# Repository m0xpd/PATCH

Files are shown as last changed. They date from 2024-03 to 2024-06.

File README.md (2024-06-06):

# PATCH
PATCH is a simple modular patchbay project for Eurorack.

<p width=100%, align="center">
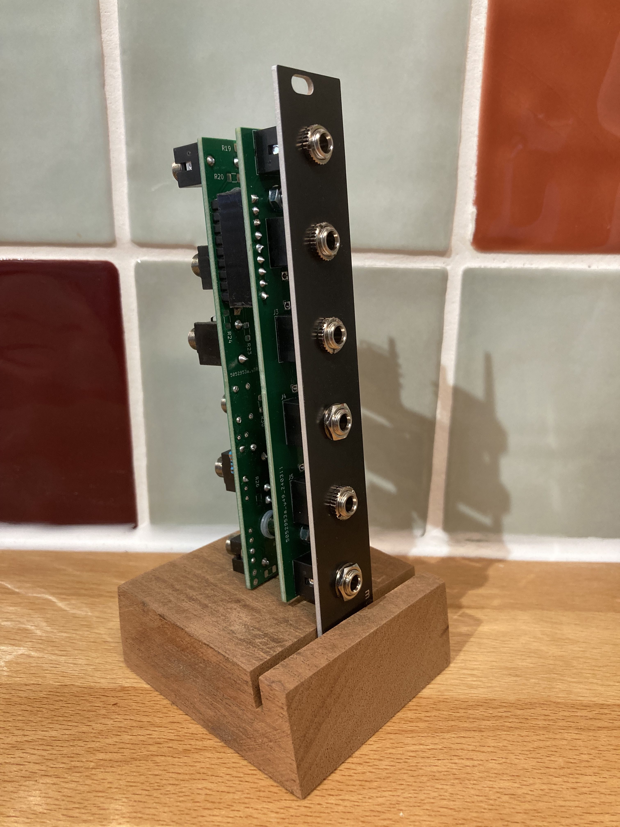
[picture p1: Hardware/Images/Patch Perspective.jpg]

</p>

PATCH started with an application to develop a simple interface to my [UMC1820 Audio Interface](https://www.behringer.com/product.html?modelCode=0805-AAN) and my [FX2000 Effects Processor](https://www.behringer.com/product.html?modelCode=P0A3P), both of which have rear-mounted audio I/O and require some input attentuators to allow them to work as I wish in my system. A patchbay is the perfect way to impose order on the tangle of wires, to avoid searching on the back of cases (especially if they're stacked or racked) and is also the logical place to implement attenuating pads, where required. 

The image below shows two PATCH patchbay modules (inside the yellow rounded rectangle) implementing the complete interface to the UMC1820 and FX2000

<p width=100%, align="center">
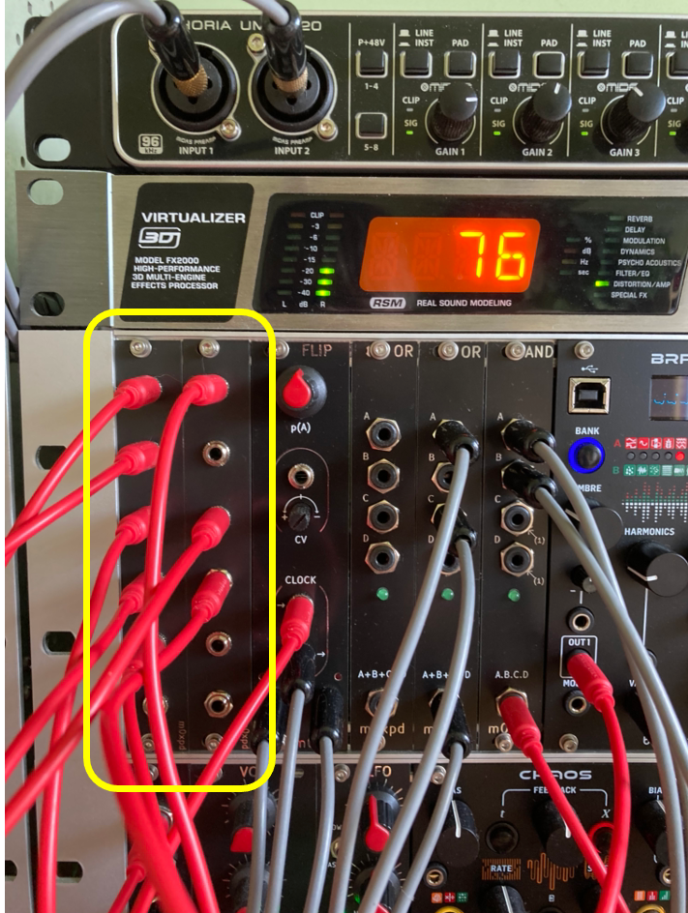
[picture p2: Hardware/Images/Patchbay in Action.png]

</p>

Note that the UMC1820 [does not need attenuators to handle modular signals directly](https://modwiggler.com/forum/viewtopic.php?p=2936306#p2936306). Indeed, it is specified to be capable of handling inputs up to +18dBu. However, this requires that the inputs are set to LINE (obviously), that the PADs are applied, and the GAIN controls are set way down near the bottom of their travel. I have been pleased to discover that in addition to service as front end of a DAW (or similar application), the UMC1820 also operates usefuly as a stand-alone mixer, with 8 channels going in and direct output to the system monitors. In this role, some external attenuation on the inputs is helpful, as it allows the GAIN controls to operate as Level 'faders' over a wider range, with more useful resolution. On the other hand, the FX2000 is specified only to handle inputs up to +4dBu and my modular was easily able to overload its inputs; an external attenuator is certainly required in this case. 

The basic PATCH configuration which services this motivating application, seen in the photos above, is realised by three components: a [front panel](https://github.com/m0xpd/PATCH/tree/main/Hardware/Front%20Panel#readme), a [socket board](https://github.com/m0xpd/PATCH/tree/main/Hardware/Socket%20Board#readme), and a [passive board](https://github.com/m0xpd/PATCH/tree/main/Hardware/Passive%20Board#readme). 

The passive board includes pi networks between the 3.5mm jack sockets at input and output of each channel and provides options to normal the 'tip switches' on the jacks to ground if the channel is configured as an input. This tip normalisation is achieved using 1206 surface mount (0 Ohm) resistors (as I figure not many people will bother to use them), whilst the rest of the board uses through-hole components. Partially populating the resistors of the pi network gives the option to set up a potential divider to drop the signal level in either direction, or to set a unity gain 'straight wire' connection. The system shown above has a 24dB pad on the top two channels and two send/return loops implemented on the next four sockets, with 12dB pads on the sends and straight-wire returns.

Populating the pads is up to you - I'm using a 15k / 1k potential divider for the -24dB and 3k3 / 1k1 potential divider for the -12dB. HOWEVER, you should remember that the device you're plugging into has finite (and possibly LOW) input impedance, which will sit in parallel with the botttom resistor of the potential divider, so either don't take the open-circuit calculations too seriously, or account for this loading in your design!

The Passive board, which makes up PATCH's standard patchbay configuration, houses a set of 3.5mm sockets which face to the rear, mirroring those on the front panel. Standard Eurorack patch leads (or other leads made up for custom applications, such as the 3.5 mm to 6.5mm right angle jacks I've made to hook up to the back of my FX2000) connect to these sockets, when the patchbay is used in the modular:

<p width=100%, align="center">
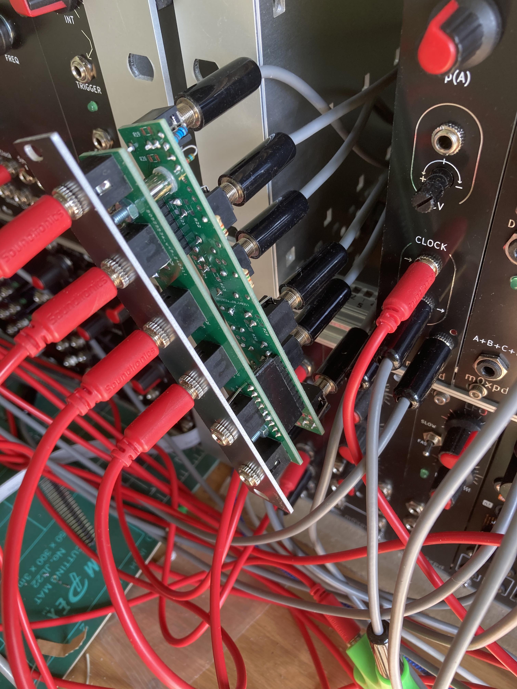
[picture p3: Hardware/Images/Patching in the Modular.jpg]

</p>

***

The minimum order quantity at [JLC](https://jlcpcb.com/) (typical of all pcb houses) for the front panel and socket board left me with some spare resources after I'd finished my interface to the Behringer "off-board" units, so I also develped a [passive multiple board](https://github.com/m0xpd/PATCH/tree/main/Hardware/Passive%20Multiple%20Board#readme), and a [buffered multiple board](https://github.com/m0xpd/PATCH/tree/main/Hardware/Buffered%20Multiple%20Board#readme) so as not to waste the relatively expensive Aluminium front panels. 

These multiples share the front panel and the socket board with the basic patchbay design, but use a different final board. 

The complete set of PATCH system panels are seen below.

<p width=100%, align="center">
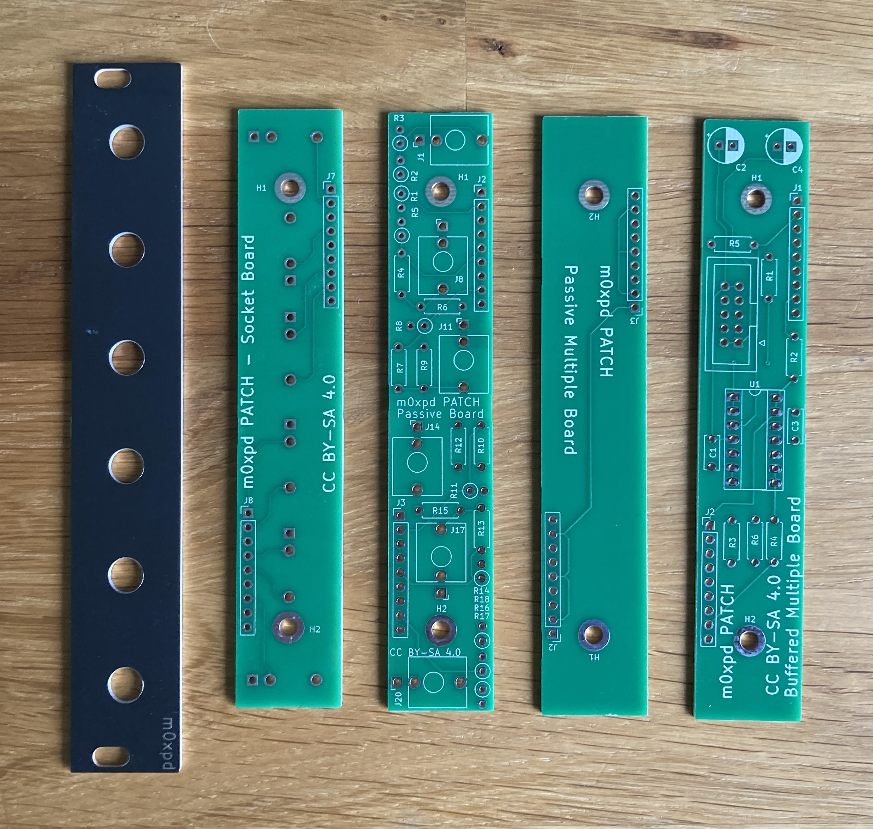
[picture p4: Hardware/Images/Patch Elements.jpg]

</p>

Both the passive multiple and the buffered multiple are organised as two 1 in, 2 out sections, with the input to the second section normalled to the output of the first, such that the multiple can be operated as two 1 -> 2 units or one 1 -> 4 unit.

A PATCH buffered multiple is seen below:

<p width=100%, align="center">
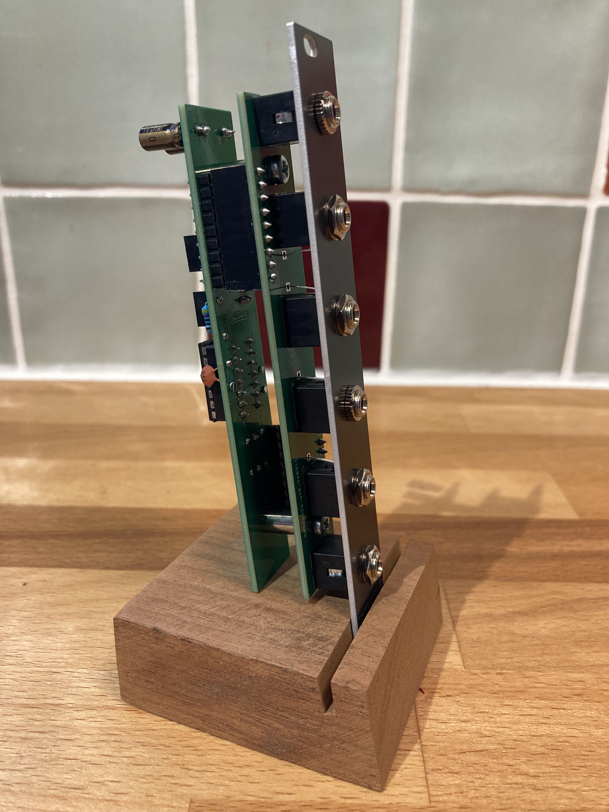
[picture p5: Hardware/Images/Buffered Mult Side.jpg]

</p>

All the system components are described in the [hardware folder](https://github.com/m0xpd/PATCH/tree/main/Hardware#readme), where schematics, PCB layouts and front panel designs are presented as [KiCad](https://www.kicad.org/) projects.

# PATCH Multicore

The PATCH system now (as at 5 June 2024) also has a multicore option, realised by a pair of boards. The multicore functionality was first suggested by "CoogLFish", within the "Issues" section of this repo and whose inspiration is acknowledged.

The boards are offered in two forms. First, the ["low budget"](https://github.com/m0xpd/PATCH/tree/main/Hardware/RJ45%20Board#readme) option uses a single UTP cable to join two modules to make a six channel multicore]. Second, the ["high end" alternative](https://github.com/m0xpd/PATCH/tree/main/Hardware/Twin%20RJ45%20Board#readme) uses two UTP cables to achieve the same goal with the possibility of slightly better crosstalk performance. This "Twin" system will also work with cables with shielded twisted pairs such as CAT8 and offer some performance advantages - but I have not yet formally tested this to determine how big the performance advantage (over either the single cable solution or UTP cables) really is. I use CAT6 cables over 1.5m and have not yet noticed issues.

# Other PATCH System Components

There may be still more additions to the PATCH system in future - I have a couple more ideas, but there are lots of other potential projects competing for attention, so watch this space, but don't hold your breath.

# License

PATCH is published under [CC BY-SA 4.0 license.](https://github.com/m0xpd/PATCH/blob/main/LICENSE.txt)

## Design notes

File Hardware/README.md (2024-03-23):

This folder contains design files for components of the PATCH modular Eurorack patchbay system.

There are schematics, PCB layouts and a Front Panel design in [KiCad](https://www.kicad.org/) format.

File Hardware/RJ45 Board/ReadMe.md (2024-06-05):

# PATCH RJ45 Board

This folder contains details of a RJ45 board, which allows the Patch system to use a CAT5 cable to provide a six channel link between two locations 
in large a modular case. This idea was propted by a suggestion made in response to the initial Patch system by "CoogLFish" - to whom I am grateful. 

The RJ45 board is seen below in populated and unpopulated form:
<p width=100%, align="center">
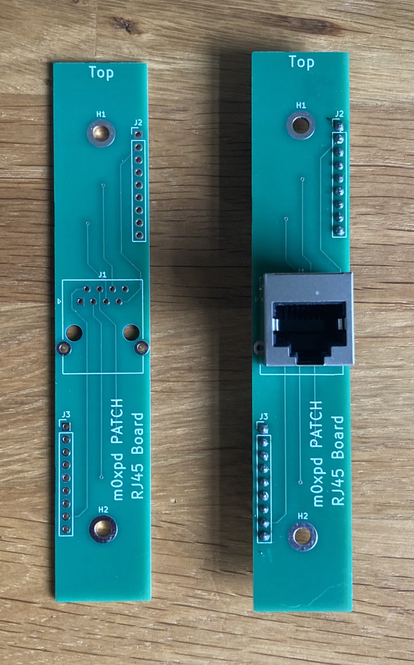
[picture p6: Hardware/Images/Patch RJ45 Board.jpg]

</p>

The signals from all six sockets on the Patch socket board are passed down six of the conductors of the RJ45 cable. This idea horrifies the engineer in me, but it must work well enough, as 7 such signals are passed down the same type of cable in [this commercial solution](https://www.doepfer.de/A1809.htm) - if it's good enough for Dieter!

The RJ-45 board plugs onto the back of a [Front Panel](https://github.com/m0xpd/PATCH/tree/main/Hardware/Front%20Panel#readme) / [socket board](https://github.com/m0xpd/PATCH/tree/main/Hardware/Socket%20Board#readme) 
combination in the same way as the rest of the PATCH family to make a full module:

<p width=100%, align="center">
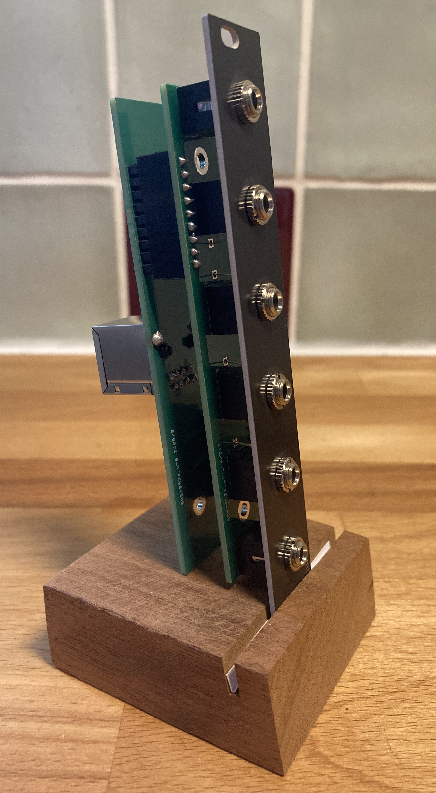
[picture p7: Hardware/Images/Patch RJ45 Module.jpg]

</p>

Two of these modules, one at either end of a standard 'network cable', make a useful multicore. In use, with a 1.5m CAT6 cable, I didn't notice any 
issues of signal loss, crosstalk or hum (etc). But the idea still horrifies me. 

So, I decided to exploit the "twisted pair" construction of network cables and build a Twin RJ45 board, which you can find [here](https://github.com/m0xpd/PATCH/tree/main/Hardware/Twin%20RJ45%20Board#readme) - to hell with the expense!

Those who want to stick with a single cable will find the KiCad design files for the single RJ-45 board in this folder - there's a KiCad project, a schematic and a PCB file.

Like the rest of the PATCH famiy, the RJ45 board is published under a CC BY-SA 4.0 [License](https://github.com/m0xpd/PATCH/blob/main/LICENSE.txt).

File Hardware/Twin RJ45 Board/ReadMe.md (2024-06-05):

# PATCH Twin RJ45 Board

This folder contains details of a Twin RJ45 board, which allows the Patch system to use two CAT5 (or better) cables to provide a six channel link 
between two locations in large a modular case. This idea was propted by a suggestion made in response to the initial PATCH system by "CoogLFish" - 
to whom I am grateful. 

The Twin RJ45 board is seen below in populated and unpopulated form:
<p width=100%, align="center">
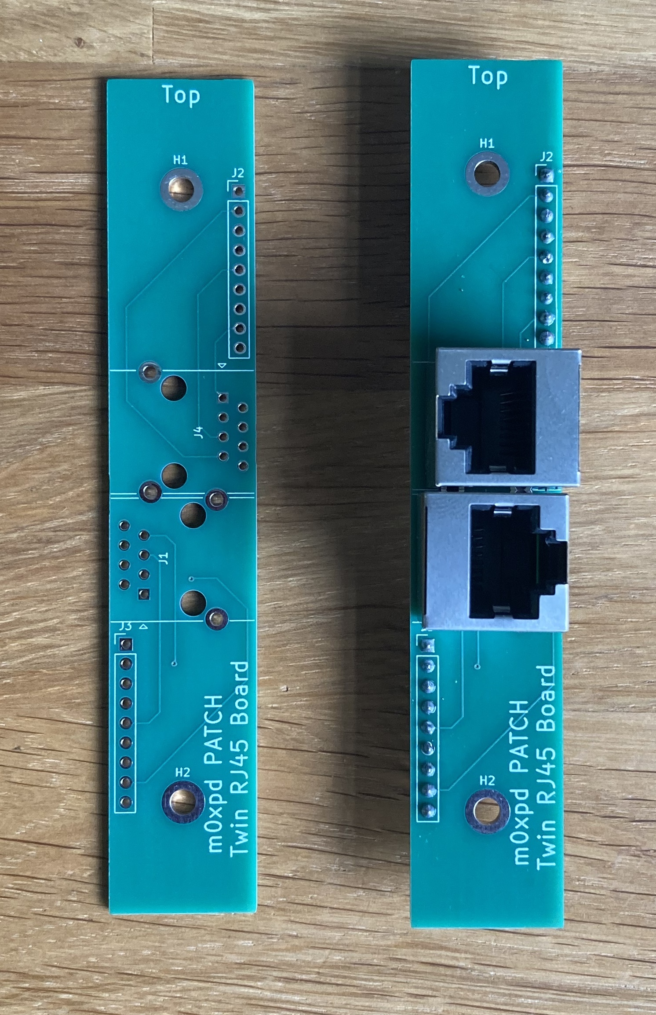
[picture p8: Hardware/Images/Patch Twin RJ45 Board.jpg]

</p>

The signals from all six sockets on the PATCH [socket board](https://github.com/m0xpd/PATCH/tree/main/Hardware/Socket%20Board#readme) are passed down three pairs of conductors in each cable connected to the two RJ45 sockets. 
These conductor pairs are arranged in twisted pairs, which should help to slightly reduce crosstalk between channels (although - of course - these 
are not balanced pairs in modular application as they would be in balanced audio interfaces or current loop data signalling). If you really want to go mad, you could use CAT8 cables with individual
screening around each pair - but if you care that much, you're probably already too busy chasing Unicorns.

The assembled module is seen below:
<p width=100%, align="center">
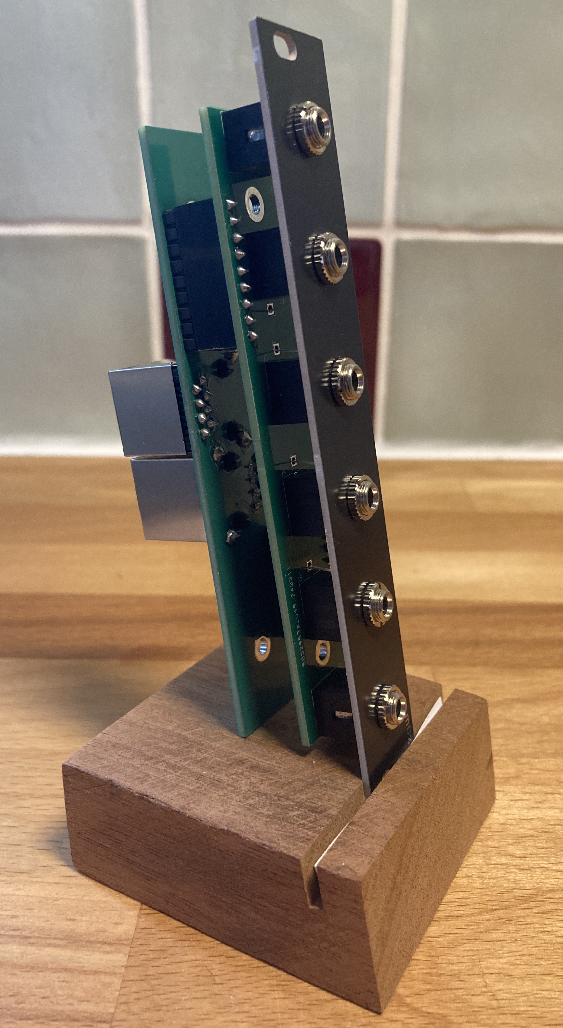
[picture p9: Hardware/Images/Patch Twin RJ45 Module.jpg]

</p>

and its role as a multicore is understood from this image:

<p width=100%, align="center">
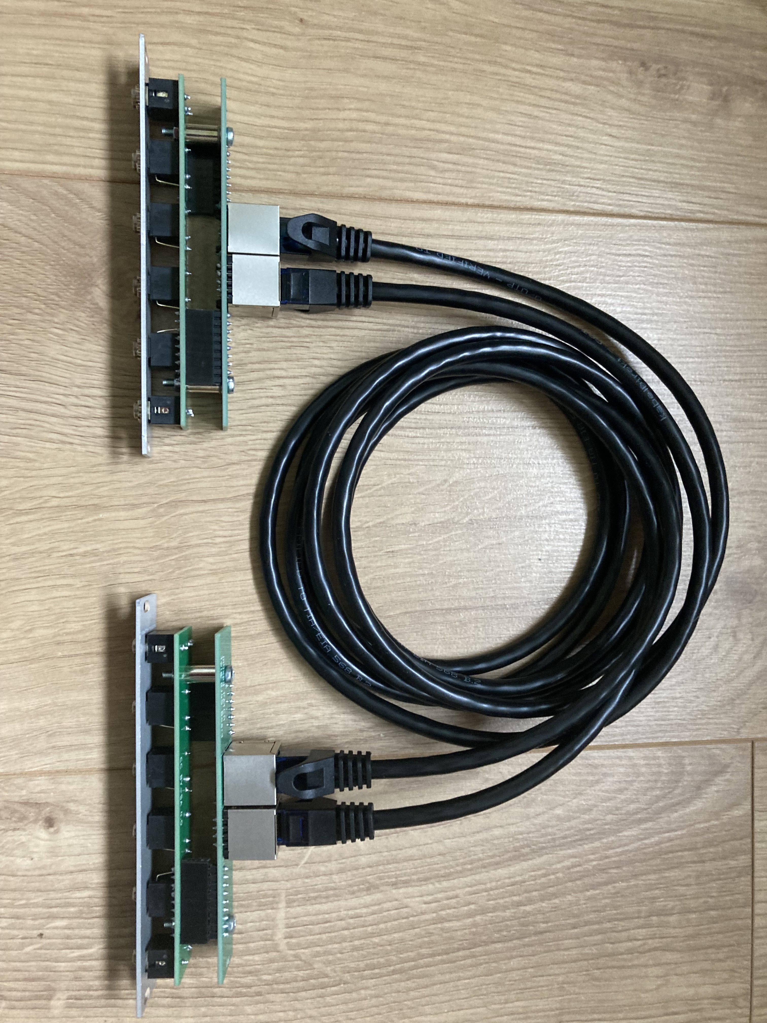
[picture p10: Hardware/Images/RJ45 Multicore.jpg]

</p>

A KiCad project, formed from a project file, a schematic and a pcb file, can be found in this folder.

Like the rest of the PATCH famiy, the Twin RJ45 board is published under a CC BY-SA 4.0 [License](https://github.com/m0xpd/PATCH/blob/main/LICENSE.txt).

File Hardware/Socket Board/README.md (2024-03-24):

# Socket Board

This folder contains design files for the "Socket Board", which is a common element of all PATCH applications. The files are in [KiCad](https://www.kicad.org/) format.

The Socket Board carries six "[Thonkiconn](https://www.thonk.co.uk/shop/thonkiconn/)" 3.5mm sockets (by which it mounts to the Front Panel) and two 9*1 0.1 inch female header sockets (by which other PATCH boards plug onto the back of the socket board. I find it convenient to cut these 9-way receptacles down from 40-way units, which I keep in stock.

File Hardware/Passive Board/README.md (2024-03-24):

# Passive Board

This folder contains design files of the "Passive Board" which, in conjunction with the Front Panel and Socket Board, implements a simple six-channel patchbay. 
The design files are presented as a [KiCad](https://www.kicad.org/) project.

The Passive Board hosts six "[Thonkiconn](https://www.thonk.co.uk/shop/thonkiconn/)" 3.5mm sockets, which mirror those on the front panel and two 9*1 0.1 inch headers, which mount the Passive Board onto 
the Socket Board. 

A set of 12 positions for 1206 surface mount resistors on the bottom side of the board allow 0 Ohm links to be fitted, which normal the Tips of the sockets 
(on the Passive and Socket board) to ground, as required.

On the top side of the board, positions are provided for through hole resistors forming a "pi network" to be placed between each socket on the Socket Board and 
the corresponding socket on the Passive Board. This allows (by leaving one resistor unpopulated) for a potential divider to be fitted to attentuate the signal 
in either direction or (by fitting a 0 Ohm link - i.e. a wire  in the resistor position at the top of th 'pi' and leaving the other resistors unpopulated), making 
the channel a straight-wire connection.

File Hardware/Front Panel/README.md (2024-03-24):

# Front Panel

This folder contains design files for a front panel for the PATCH system, expressed as a [KiCad](https://www.kicad.org/) project.

Remember that the schematic is 'empty' - the front panel has no electrical connections.

The front panel has no labels/annotation, because each instance of the system will be put to different use; you can add labels convenient to your own application if you need to.

I find it convenient at least to use different nuts (i.e. knurled or hex) on the sockets to remind me which are inputs and which are outputs, from which I can remember the configuration of the PATCH module. If you are less stingy than me, you could even use coloured nuts!

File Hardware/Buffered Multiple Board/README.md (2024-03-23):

# Buffered Multiple Board

This folder contains design files for the Buffered Multiple Board which (in conjuntion with the Socket Board and Front Panel) form an active, Buffered Multiple. 
The design files are presented as a [KiCad](https://www.kicad.org/) project.

The Buffered Multiple Board hosts two 9 * 1, 0.1 inch headers (to mount it on to the Socket Board),  a standard 2*5 Eurorack Power Header and filtering capacitors. 
It also hosts a quad op-amp (I used a TL084, but anything similar will work), the stages of which are used as voltage followers, and a few resistors to set the 
input and source impedance. 

The resulting buffered multiple is organised as two 1 in, 2 out sections, with the input to the second section normalled to the output of the first, 
such that the module can be operated as two 1 -> 2 multiples or one 1 -> 4 multiple.

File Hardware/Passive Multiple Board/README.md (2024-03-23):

# Passive Multiple Board

This folder contains design files for the Passive Multiple Board which (in conjuntion with the Socket Board and Front Panel) form a Passive Multiple. 
The design files are presented as a [KiCad](https://www.kicad.org/) project.

The Passive Multiple Board is trivial, hosting only two 9*1 0.1 inch headers (to mount it on to the Socket Board) and containing tracks between the 
poles of these headers to make the electrical connections which define the circuit (see the Schematic).

The resulting passive multiple is organised as two 1 in, 2 out sections, with the input to the second section normalled to the output of the first, 
such that the module can be operated as two 1 -> 2 multiples or one 1 -> 4 multiple.

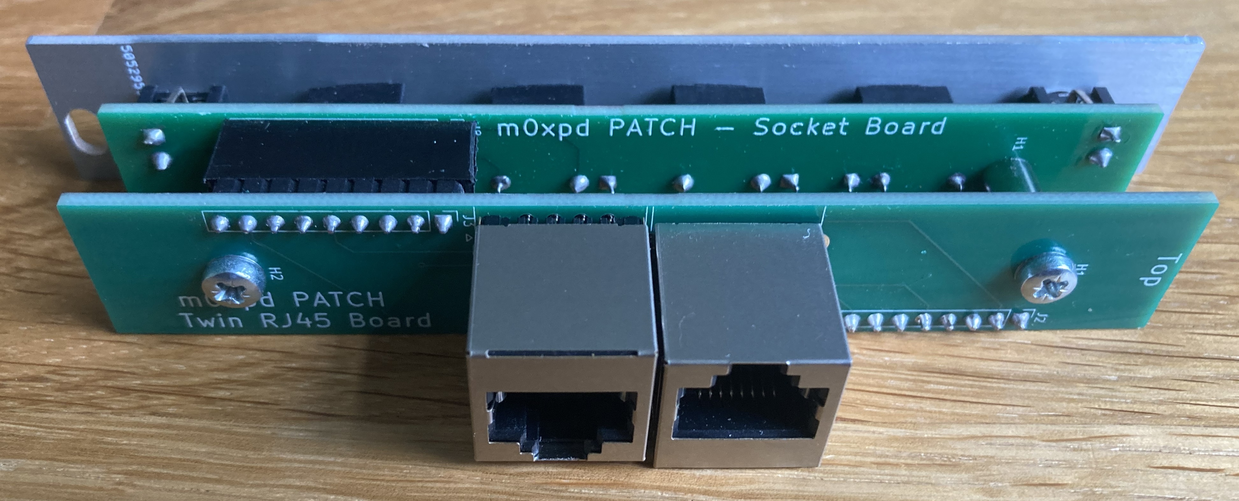
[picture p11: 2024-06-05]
Hardware/Images/Twin RJ45 Module Rear.jpg

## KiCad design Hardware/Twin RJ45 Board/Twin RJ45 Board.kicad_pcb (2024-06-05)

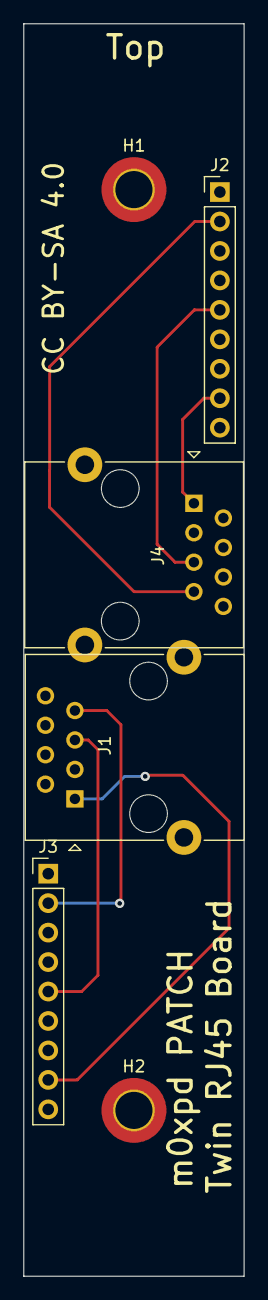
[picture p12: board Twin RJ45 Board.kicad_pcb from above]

Board: 2 copper layers, 19.0 x 108.0 mm, 6 parts (0 on the bottom side), 7 nets.

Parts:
H1, H2: MountingHole_Pad; MountingHole_3.2mm_M3_DIN965_Pad_TopBottom
J1, J4: RJ45_Shielded; RJ45_Ninigi_GE
J2, J3: Conn_01x09; PinHeader_1x09_P2.54mm_Vertical

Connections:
GND: H1.1, H2.1, J1.2, J1.3, J1.4, J1.6, J1.8, J1.SH, J2.3, J2.6, J2.9, J3.3, J3.6, J3.9, J4.2, J4.3, J4.4, J4.6, J4.8, J4.SH
unnamed: J2.2, J4.7
unnamed: J2.5, J4.5
unnamed: J2.8, J4.1
unnamed: J1.7, J3.2
unnamed: J1.5, J3.5
unnamed: J1.1, J3.8

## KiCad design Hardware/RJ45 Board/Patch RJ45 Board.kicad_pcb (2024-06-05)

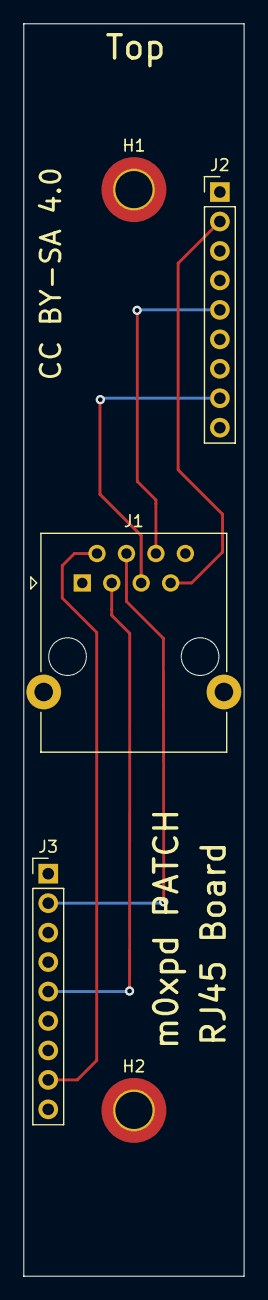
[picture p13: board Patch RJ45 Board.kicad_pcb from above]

Board: 2 copper layers, 19.0 x 108.0 mm, 5 parts (0 on the bottom side), 7 nets.

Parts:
H1, H2: MountingHole_Pad; MountingHole_3.2mm_M3_DIN965_Pad_TopBottom
J1: RJ45_Shielded; RJ45_Ninigi_GE
J2, J3: Conn_01x09; PinHeader_1x09_P2.54mm_Vertical

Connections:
GND: H1.1, H2.1, J1.1, J1.8, J1.SH, J2.3, J2.6, J2.9, J3.3, J3.6, J3.9
unnamed: J1.7, J2.2
unnamed: J1.6, J2.5
unnamed: J1.5, J2.8
unnamed: J1.4, J3.2
unnamed: J1.3, J3.5
unnamed: J1.2, J3.8

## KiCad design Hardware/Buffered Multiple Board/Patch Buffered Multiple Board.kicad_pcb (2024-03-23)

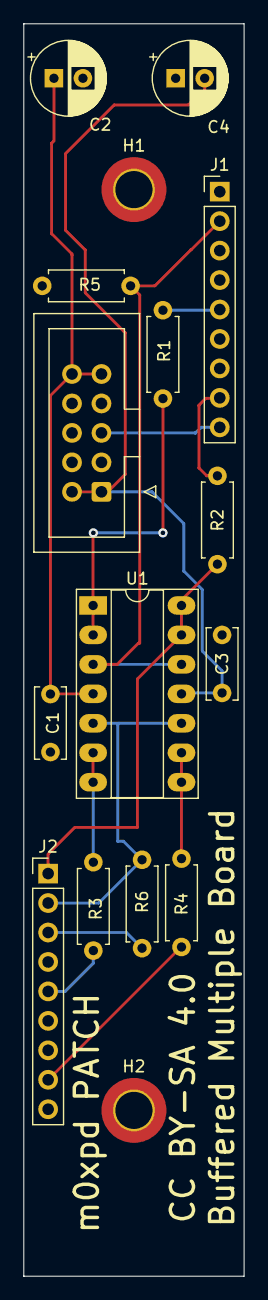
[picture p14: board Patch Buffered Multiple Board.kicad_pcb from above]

Board: 2 copper layers, 19.0 x 108.0 mm, 16 parts (0 on the bottom side), 13 nets.

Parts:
C1, C3: 0.1u; C_Disc_D6.0mm_W2.5mm_P5.00mm
C2, C4: 22u; CP_Radial_D6.3mm_P2.50mm
H1, H2: MountingHole_Pad; MountingHole_3.2mm_M3_DIN965_Pad_TopBottom
J1, J2: Conn_01x09; PinHeader_1x09_P2.54mm_Vertical
R1, R2, R3, R4, R5, R6: R; R_Axial_DIN0207_L6.3mm_D2.5mm_P7.62mm_Horizontal
U1: TL084; DIP-14_W7.62mm_Socket_LongPads
X1: 2510-; IDC-Header_2x05_P2.54mm_Vertical

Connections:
+12V: C1.1, C2.1, U1.4 (V+), X1.9 (KL), X1.10 (KL)
-12V: C3.2, C4.2, U1.11 (V-), X1.1 (KL), X1.2 (KL)
GND: C1.2, C2.2, C3.1, C4.1, H1.1, H2.1, J1.3, J1.6, J1.9, J2.3, J2.6, J2.9, R5.1, R6.1, X1.3 (KL), X1.4 (KL), X1.5 (KL), X1.6 (KL), X1.7 (KL), X1.8 (KL)
IN1: J1.2, R5.2, U1.3 (+), U1.12 (+)
IN2: J2.2, R6.2, U1.5 (+), U1.10 (+)
unnamed: R1.1, U1.1, U1.2 (-)
unnamed: R3.1, U1.6 (-), U1.7
unnamed: R4.1, U1.8, U1.9 (-)
OUT1: J1.5, R1.2
OUT2: J1.8, R2.2
OUT2A: J2.1, R2.1, U1.13 (-), U1.14
OUT3: J2.5, R3.2
OUT4: J2.8, R4.2

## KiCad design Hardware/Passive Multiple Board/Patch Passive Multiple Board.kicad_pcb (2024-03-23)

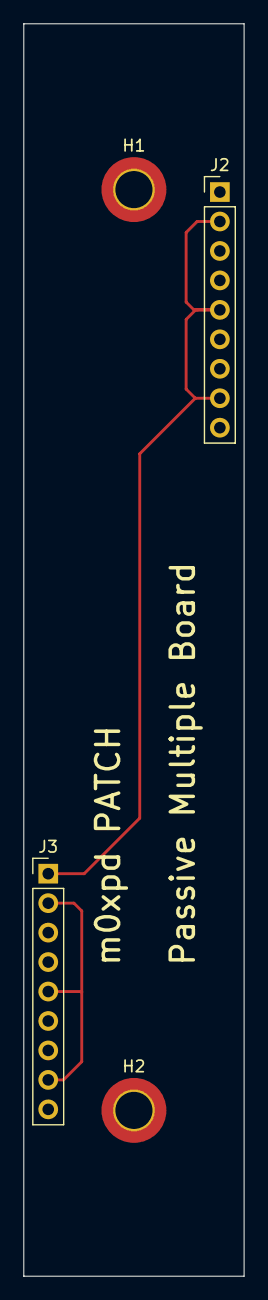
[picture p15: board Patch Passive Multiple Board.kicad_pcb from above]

Board: 2 copper layers, 19.0 x 108.0 mm, 4 parts (0 on the bottom side), 3 nets.

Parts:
H1, H2: MountingHole_Pad; MountingHole_3.2mm_M3_DIN965_Pad_TopBottom
J2, J3: Conn_01x09; PinHeader_1x09_P2.54mm_Vertical

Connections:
GND: H1.1, H2.1, J2.3, J2.6, J2.9, J3.3, J3.6, J3.9
unnamed: J2.2, J2.5, J2.8, J3.1
unnamed: J3.2, J3.5, J3.8

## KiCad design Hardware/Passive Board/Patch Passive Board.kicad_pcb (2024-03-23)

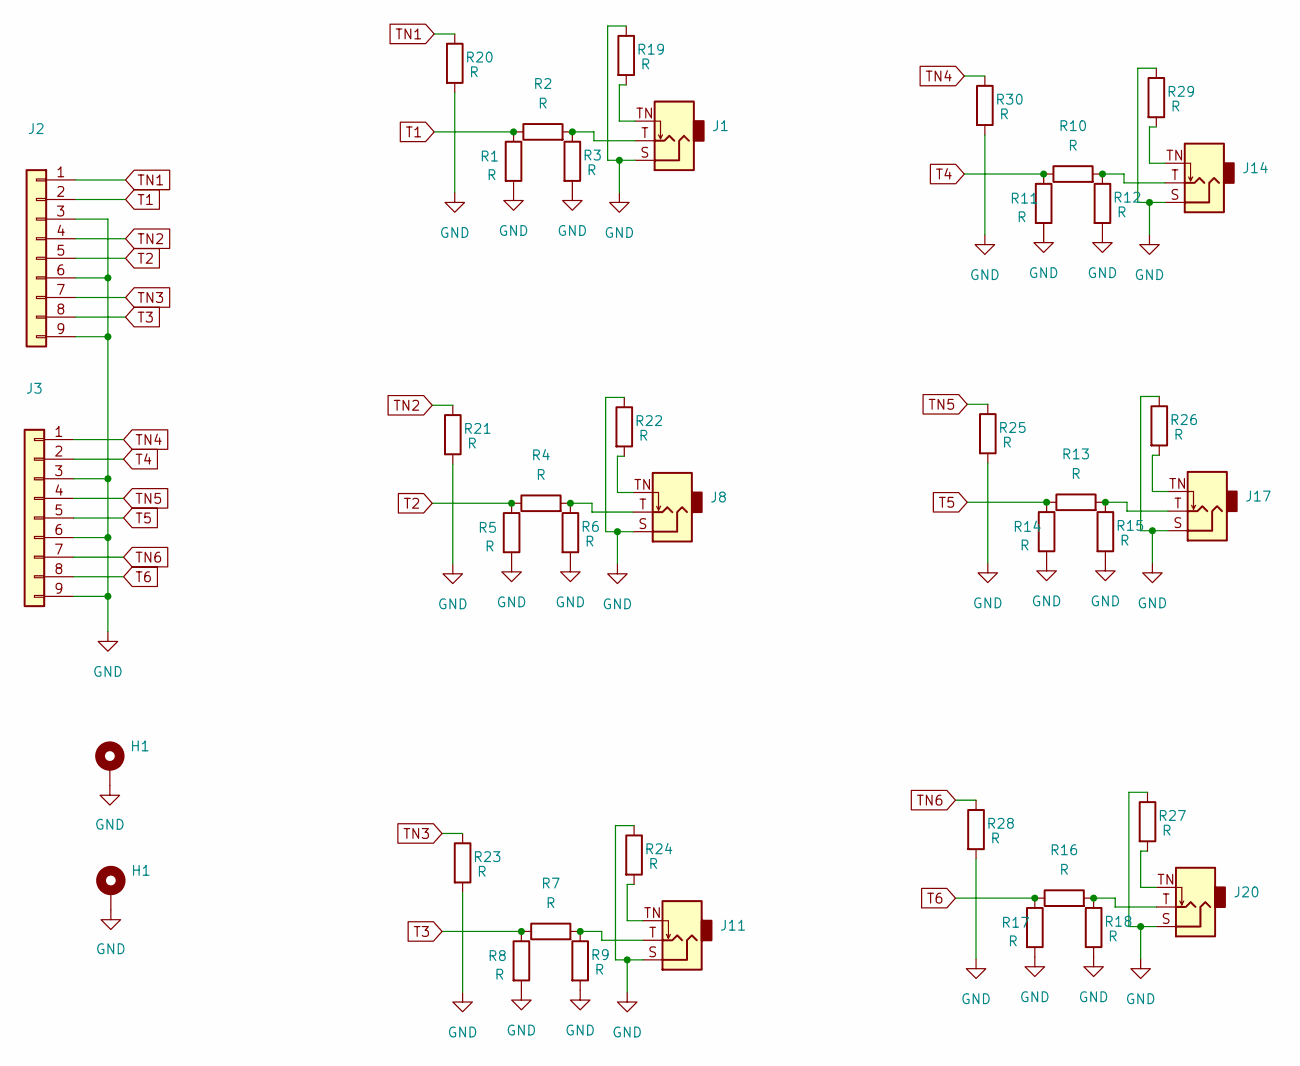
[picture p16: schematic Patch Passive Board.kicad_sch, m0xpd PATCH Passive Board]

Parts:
H1: MountingHole_Pad; MountingHole_3.2mm_M3_DIN965_Pad_TopBottom
J1, J8, J11, J14, J17, J20: AudioJack2_SwitchT; Jack_3.5mm_QingPu_WQP-PJ398SM_Vertical_CircularHoles
J2, J3: Conn_01x09; PinHeader_1x09_P2.54mm_Vertical
R1, R2, R3, R5, R8, R11, R14, R16, R17, R18: R; R_Axial_DIN0207_L6.3mm_D2.5mm_P2.54mm_Vertical
R4, R6, R7, R9, R10, R12, R13, R15: R; R_Axial_DIN0207_L6.3mm_D2.5mm_P7.62mm_Horizontal
R19, R20, R21, R22, R23, R24, R25, R26, R27, R28, R29, R30: R; R_1206_3216Metric_Pad1.30x1.75mm_HandSolder

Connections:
GND: H1.1, J1.S, J2.3, J2.6, J2.9, J3.3, J3.6, J3.9, J8.S, J11.S, J14.S, J17.S, J20.S, R1.2, R3.2, R5.2, R6.2, R8.2, R9.2, R11.2, R12.2, R14.2, R15.2, R17.2, R18.2, R19.1, R20.2, R21.2, R22.1, R23.2, R24.1, R25.2, R26.1, R27.1, R28.2, R29.1, R30.2; also elsewhere on the board
unnamed: J1.T, R2.2, R3.1
unnamed: J1.TN, R19.2
unnamed: J8.T, R4.2, R6.1
unnamed: J8.TN, R22.2
unnamed: J11.T, R7.2, R9.1
unnamed: J11.TN, R24.2
unnamed: J14.T, R10.2, R12.1
unnamed: J14.TN, R29.2
unnamed: J17.T, R13.2, R15.1
unnamed: J17.TN, R26.2
unnamed: J20.T, R16.2, R18.1
unnamed: J20.TN, R27.2
T1: J2.2, R1.1, R2.1
T2: J2.5, R4.1, R5.1
T3: J2.8, R7.1, R8.1
T4: J3.2, R10.1, R11.1
T5: J3.5, R13.1, R14.1
T6: J3.8, R16.1, R17.1
TN1: J2.1, R20.1
TN2: J2.4, R21.1
TN3: J2.7, R23.1
TN4: J3.1, R30.1
TN5: J3.4, R25.1
TN6: J3.7, R28.1

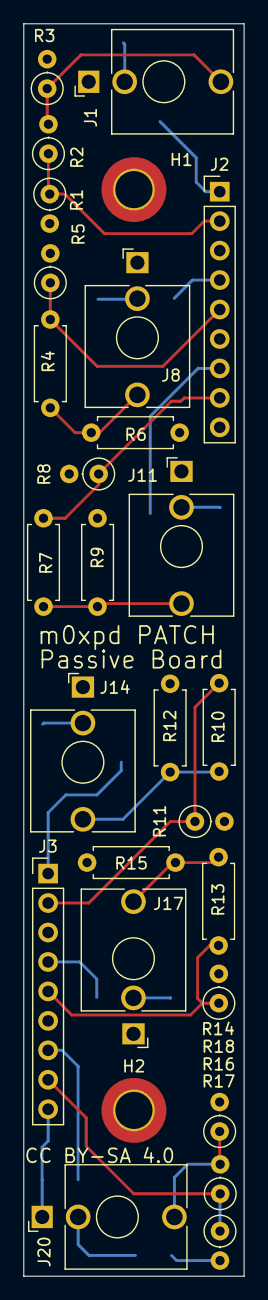
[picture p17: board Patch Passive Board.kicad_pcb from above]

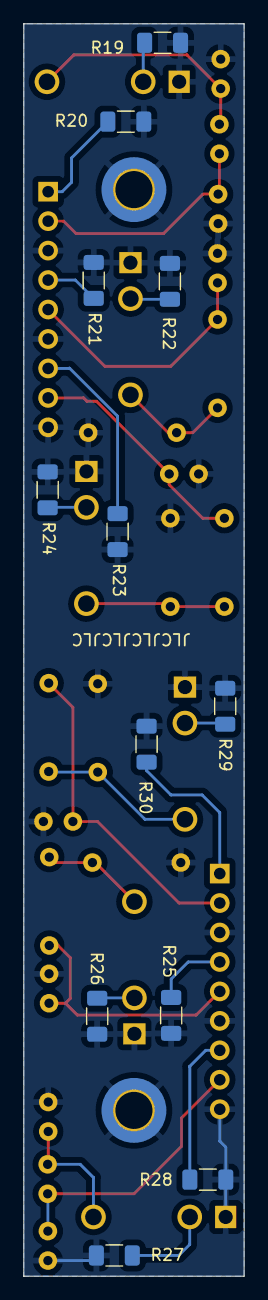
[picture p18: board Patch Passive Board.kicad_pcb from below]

Board: 2 copper layers, 19.0 x 108.0 mm, 40 parts (12 on the bottom side), 25 nets.

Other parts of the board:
H2: MountingHole_Pad; MountingHole_3.2mm_M3_DIN965_Pad_TopBottom

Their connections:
GND: H2.1; also elsewhere on the board

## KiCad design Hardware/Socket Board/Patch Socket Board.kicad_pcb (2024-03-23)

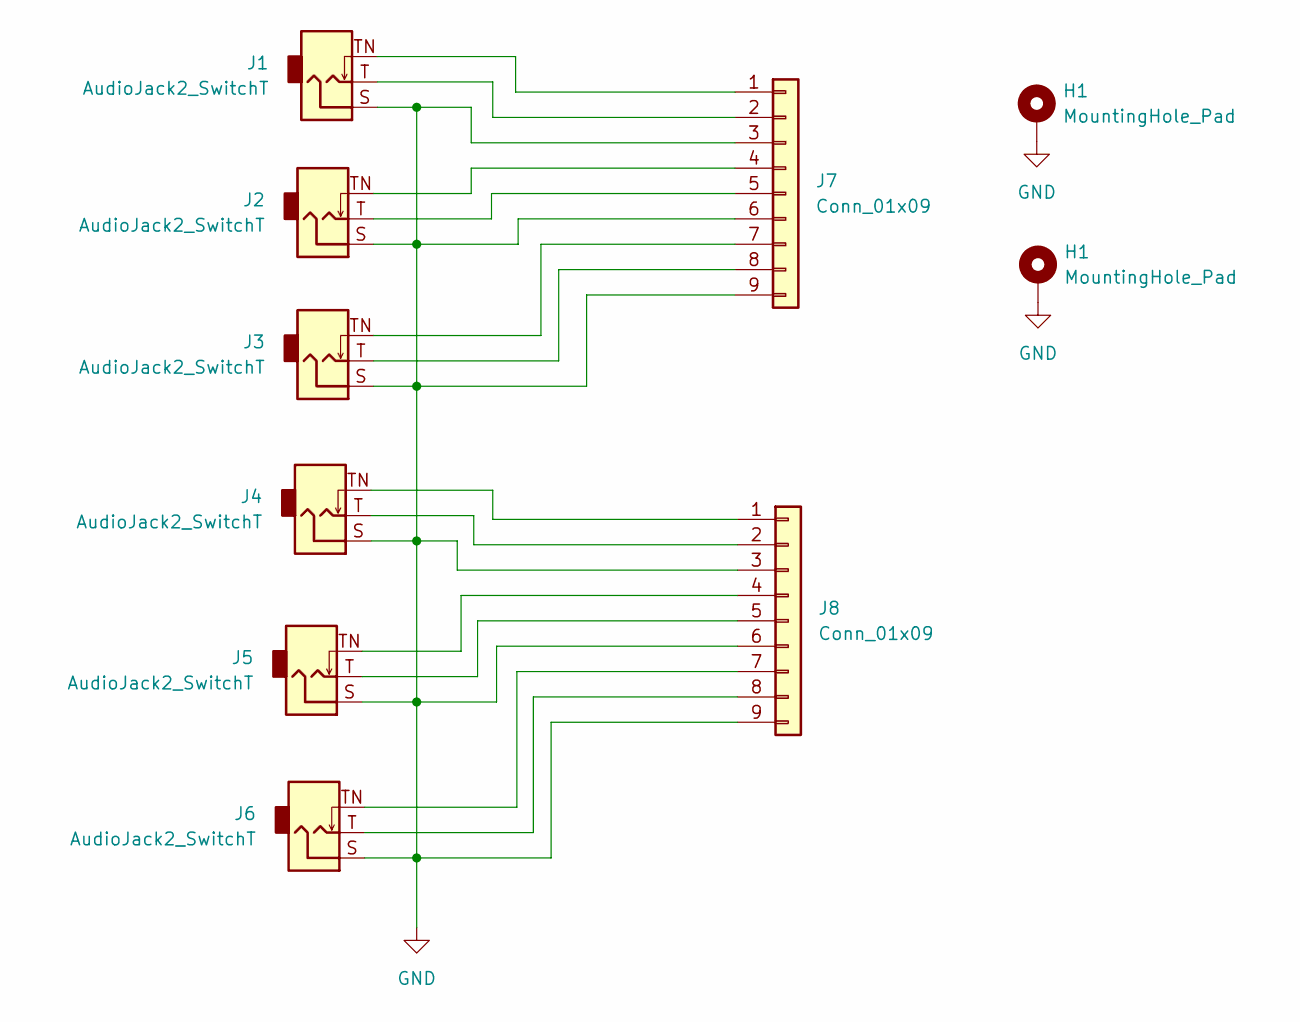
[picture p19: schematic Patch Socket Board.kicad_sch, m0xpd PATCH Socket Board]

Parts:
H1: MountingHole_Pad; MountingHole_3.2mm_M3_DIN965_Pad_TopBottom
J1, J2, J3, J4, J5, J6: AudioJack2_SwitchT; Jack_3.5mm_QingPu_WQP-PJ398SM_Vertical_CircularHoles
J7, J8: Conn_01x09; PinHeader_1x09_P2.54mm_Vertical

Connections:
GND: H1.1, J1.S, J2.S, J3.S, J4.S, J5.S, J6.S, J7.3, J7.6, J7.9, J8.3, J8.6, J8.9; also elsewhere on the board
unnamed: J1.TN, J7.1
unnamed: J1.T, J7.2
unnamed: J2.TN, J7.4
unnamed: J2.T, J7.5
unnamed: J3.TN, J7.7
unnamed: J3.T, J7.8
unnamed: J4.TN, J8.1
unnamed: J4.T, J8.2
unnamed: J5.TN, J8.4
unnamed: J5.T, J8.5
unnamed: J6.TN, J8.7
unnamed: J6.T, J8.8

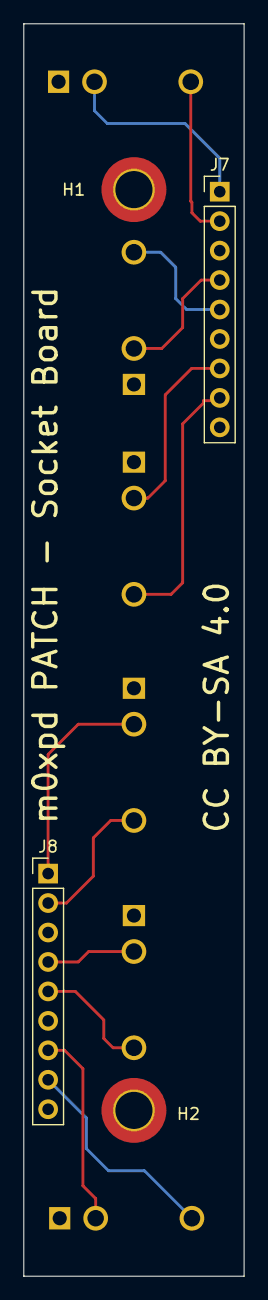
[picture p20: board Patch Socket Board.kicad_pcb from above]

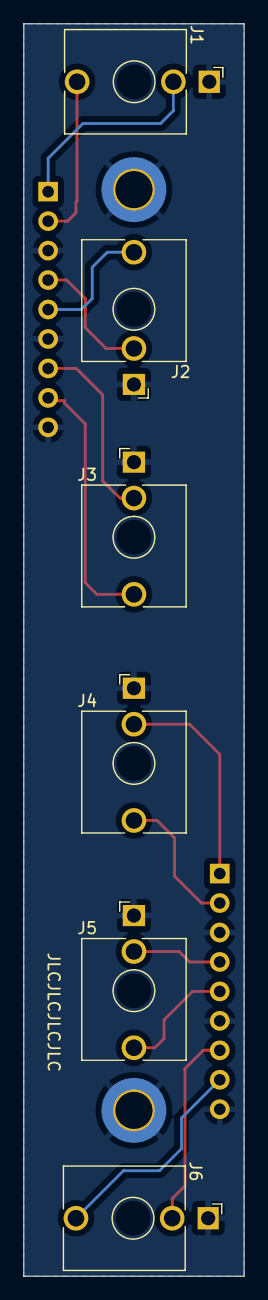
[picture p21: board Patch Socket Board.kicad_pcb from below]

Board: 2 copper layers, 19.0 x 108.0 mm, 10 parts (6 on the bottom side), 13 nets.

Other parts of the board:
H2: MountingHole_Pad; MountingHole_3.2mm_M3_DIN965_Pad_TopBottom

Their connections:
GND: H2.1; also elsewhere on the board

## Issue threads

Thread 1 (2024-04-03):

RJ45 addon-board for PATCH

CoogLFish, 2024-04-03:
Hello Paul,
this obviously isn't an issue but a suggestion. Wouldn't it be a nice idea to include a RJ45-board into your collection to _internally_ connect two cases via an ethernet cable? I know there are several solutions commercially available (including Doepfer) to accomplish this _externally_, but not inside the cases.

m0xpd, 2024-04-04:
Thanks for raising this interesting idea, which falls nicely within the scope of 'Patch'. I certainly hadn't thought of it.

I've heard of the Doepfer (etc) solutions, but I don't know anything about them. To be honest, I first assumed they were active devices, which made a local network connection over the cable and encoded the data for transmission. But on reflection, I guess that either a buffered connection or even a simple passive connection over the twisted pairs of a 'CatX' cable would work.

Thanks again for raising this.

awonak, 2024-04-24:
I have been working on a few passive patch bay via Ethernet modules if you'd like to check them out for any inspiration: https://github.com/awonak/ether-twin

Closed 2024-04-05.

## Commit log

2024-03-23 Rename Patch Front Panel.kicad_pcb to Hardware/Patch Front Panel.kicad_pcb
    [Patch Front Panel.kicad_pcb]
2024-03-23 Rename Patch Front Panel.kicad_pro to Hardware/Patch Front Panel.kicad_pro
2024-03-23 Rename Patch Front Panel.kicad_sch to Hardware/Patch Front Panel.kicad_sch
    [Patch Front Panel.kicad_sch]
2024-03-23 Rename Hardware/Patch Front Panel.kicad_pcb to Hardware/Front Panel/Patch Front Panel.kicad_pcb
    [Patch Front Panel.kicad_pcb]
2024-03-23 Rename Hardware/Patch Front Panel.kicad_pro to Hardware/Front Panel/Patch Front Panel.kicad_pro
2024-03-23 Rename Hardware/Patch Front Panel.kicad_sch to Hardware/Front Panel/Patch Front Panel.kicad_sch
    [Patch Front Panel.kicad_sch]
2024-03-23 Rename Hardware/Patch Socket Board.kicad_pro to Hardware/Socket Board/Patch Socket Board.kicad_pro
2024-03-23 Rename Hardware/Patch Passive Board.kicad_pro to Hardware/Passive Board/Patch Passive Board.kicad_pro
2024-03-23 Rename Hardware/Patch Passive Multiple Board.kicad_pro to Hardware/Passive Multiple Board/Patch Passive Multiple Board.kicad_pro
2024-03-23 Rename Hardware/Patch Buffered Multiple Board.kicad_pcb to Hardware/Buffered Multiple Board/Patch Buffered Multiple Board.kicad_pcb
    [Patch Buffered Multiple Board.kicad_pcb]
2024-06-05 Rename Hardware/Patch RJ45 Board.jpg to Hardware/Images/Patch RJ45 Board.jpg
2024-06-05 Rename Hardware/Patch Twin RJ45 Board.jpg to Hardware/Images/Patch Twin RJ45 Board.jpg
2024-06-05 Rename Hardware/Patch RJ45 Board.kicad_pcb to Hardware/RJ45 Board/Patch RJ45 Board.kicad_pcb
    [Patch RJ45 Board.kicad_pcb]
2024-06-05 Rename Hardware/Patch RJ45 Board.kicad_pro to Hardware/RJ45 Board/Patch RJ45 Board.kicad_pro
2024-06-05 Rename Hardware/Patch RJ45 Board.kicad_sch to Hardware/RJ45 Board/Patch RJ45 Board.kicad_sch
    [Patch RJ45 Board.kicad_sch]
2024-06-05 Rename Hardware/Twin RJ45 Board.kicad_pcb to Hardware/Twin RJ45 Board/Twin RJ45 Board.kicad_pcb
    [Twin RJ45 Board.kicad_pcb]
2024-06-05 Rename Hardware/Twin RJ45 Board.kicad_pro to Hardware/Twin RJ 45 Board/Twin RJ45 Board.kicad_pro
2024-06-05 Rename Hardware/Twin RJ45 Board.kicad_sch to Hardware/Twin RJ45 Board/Twin RJ45 Board.kicad_sch
    [Twin RJ45 Board.kicad_sch]
2024-06-05 Rename Hardware/Twin RJ45 Board.kicad_pro to Hardware/Twin RJ45 Board/Twin RJ45 Board.kicad_pro
